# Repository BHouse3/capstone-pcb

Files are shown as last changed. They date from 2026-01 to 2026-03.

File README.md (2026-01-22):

# capstone-pcb

All files and documentation for PCB integration.

## Timeline

01/12/2026 - Created project repo and initial hierarchical KiCad structure. Found DFRobot's rp2350 module footprint.

01/13/2026 - Ethan created symbol for rp2350 module.

01/14/2026 - Created fuel gauge schematic with LC709203FQH-01TWG. Evaluating charging and voltage conversion methodology. 

01/15/2026 - Redesign of entire power subsystem. Utilizing TP4057 charger on board RP2350 module. DW01A + FS8205A protection circuitry. TPS61023 5V boost converter. BQ27441-G1 fuel gauge. Minimizes cost and number of components in power system. Ethan created L1 schematic with labels and wires for the symbol created on 01/13/2026. The symbol was also edited to correct labeling errors.

01/17/2026 - Power schematic starting point based on datasheet implementations. Will work to further verify. Changed MCU labels to global labels.

01/20/2026 - UI schematic finished. External connector symbols added. Hierarchical label issue. Washout detection schematic finished. Motor schematic finished.

01/22/2026 - Fixed critical polarity issue on flyback diodes. Hierarchical label assignment. Added missing I2C labels on power system

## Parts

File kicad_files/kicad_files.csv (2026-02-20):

Reference | Qty | Value | DNP | Exclude from BOM | Exclude from Board | Footprint | Datasheet
.1 | 1 | DFRobot RP2350 Module |  |  |  | rp2350_footprint:DFR1188-DIP
C2 | 1 | 1.0uF
C3,C10 | 2 | 10uF |  |  |  |  | ~
C4 | 1 | 0.47uF
C5,C6 | 2 | 22uF
C7,C8,C9 | 3 | 10nF |  |  |  |  | ~
C11 | 1 | 1uF |  |  |  |  | ~
C12 | 1 | 220 uF
C14 | 1 | 0.1uF
D1 | 1 | 1N4001 |  |  |  | Diode_THT:D_DO-41_SOD81_P10.16mm_Horizontal | http://www.vishay.com/docs/88503/1n4001.pdf
D3 | 1 | 1N914 |  |  |  | Diode_THT:D_DO-35_SOD27_P7.62mm_Horizontal | http://www.vishay.com/docs/85622/1n914.pdf
J1 | 1 | Battery Connection |  |  |  |  | ~
J2,J6 | 2 | Servo Connection |  |  |  |  | ~
J3 | 1 | DC Motor Connection |  |  |  |  | ~
J4 | 1 | Washout Ultrasonic Sensor Connection |  |  |  |  | ~
J5 | 1 | Water Sensor Connection |  |  |  |  | ~
J7 | 1 | Larvicide Level Ultrasonic Sensor Connection |  |  |  |  | ~
L1 | 1 | 1uH |  |  |  |  | ~
Q1 | 1 | FS8205A |  |  |  | Fs8205a:SOT-23-6L_TCP | FS8205A
Q2,Q3,Q4,Q5,Q7 | 5 | NMOS |  |  |  |  | https://ngspice.sourceforge.io/docs/ngspice-html-manual/manual.xhtml#cha_MOSFETs
R1 | 1 | 100 |  |  |  |  | ~
R2 | 1 | 1000 |  |  |  |  | ~
R3,R4,R5 | 3 | 5100 |  |  |  |  | ~
R6,R10,R11,R22,R23,R24,R30 | 7 | 10k |  |  |  |  | ~
R7 | 1 | 0.01 / 1% |  |  |  |  | ~
R8 | 1 | 732k |  |  |  |  | ~
R9,R13,R16,R17,R18,R19 | 6 | 100k |  |  |  |  | ~
R12,R21,R26,R27 | 4 | 1k |  |  |  |  | ~
R14 | 1 | 200k |  |  |  |  | ~
R15 | 1 | 470k |  |  |  |  | ~
R20 | 1 | 20k |  |  |  |  | ~
R28,R29 | 2 | 2k |  |  |  |  | ~
U1 | 1 | BQ27441DRZR-G1A |  |  |  | Package_SON:Texas_S-PDSO-N12 | http://www.ti.com/lit/ds/symlink/bq27441-g1.pdf
U2 | 1 | DW01A |  |  |  | Package_TO_SOT_SMD:SOT-23-6 | https://hmsemi.com/downfile/DW01A.PDF
U3 | 1 | TPS61023DRLR |  |  |  | TPS61023:DRL0006A | https://www.ti.com/lit/gpn/tps61023
U4 | 1 | LM311 |  |  |  | LM311:D8 | https://www.st.com/resource/en/datasheet/lm311.pdf
U5,U6 | 2 | LMC555CMMX_NOPB |  |  |  | LMC555CMMX_NOPB:SOP65P490X110-8N

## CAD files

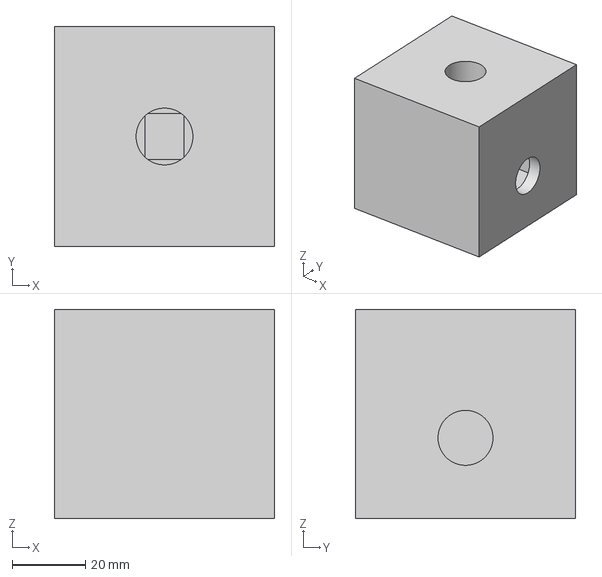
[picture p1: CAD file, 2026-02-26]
LarvicideDispersionSubsystem(2-25-2026)/Assembly 1 - Motor Housing.3mf
60.0 x 60.0 x 57.0 mm

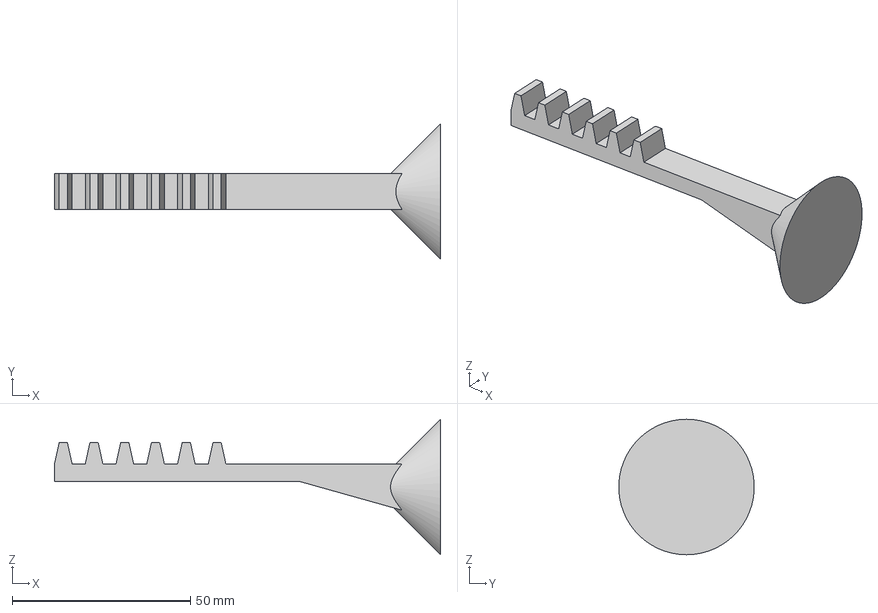
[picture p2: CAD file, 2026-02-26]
LarvicideDispersionSubsystem(2-25-2026)/Assembly 1 - Rack.3mf
108.4 x 38.0 x 38.1 mm

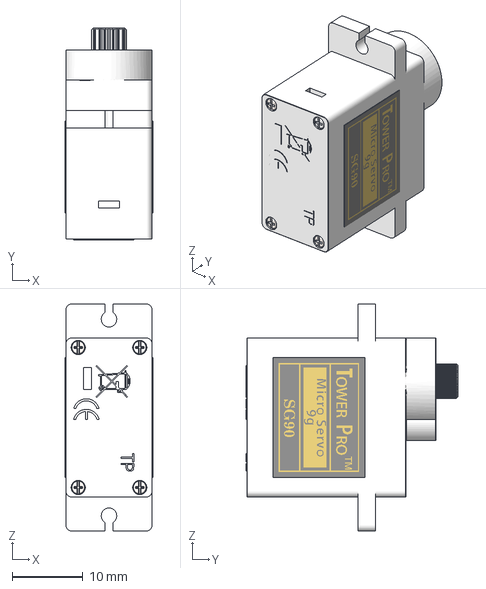
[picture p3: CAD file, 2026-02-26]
LarvicideDispersionSubsystem(2-25-2026)/Assembly 1 - Servo.3mf
12.4 x 29.9 x 32.1 mm

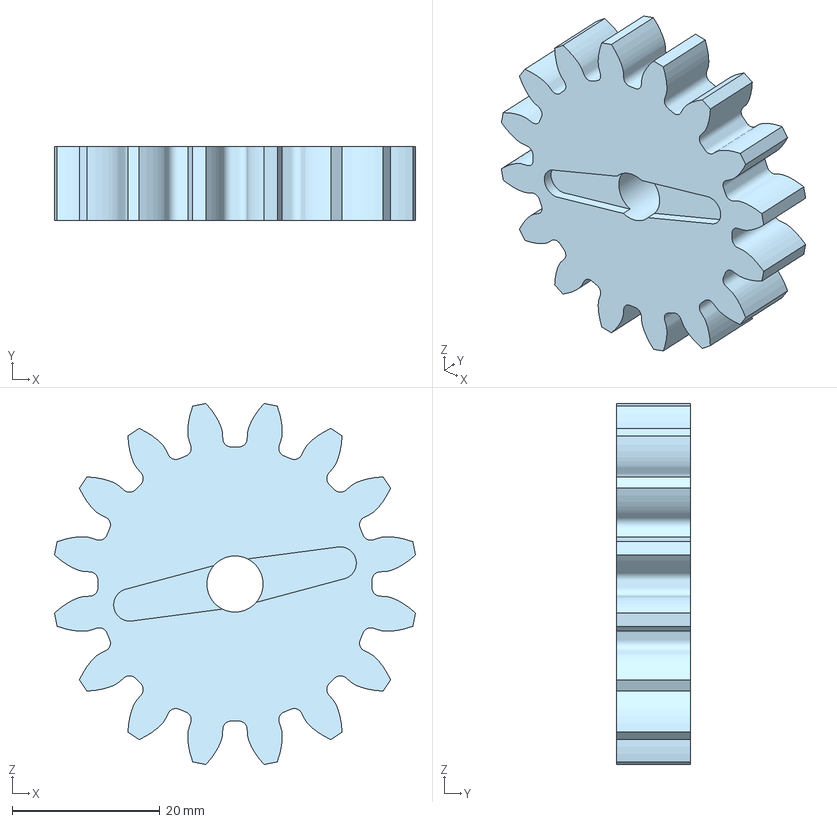
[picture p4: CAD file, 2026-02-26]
LarvicideDispersionSubsystem(2-25-2026)/Assembly 1 - Spur gear (16 teeth).3mf
48.9 x 10.0 x 48.9 mm

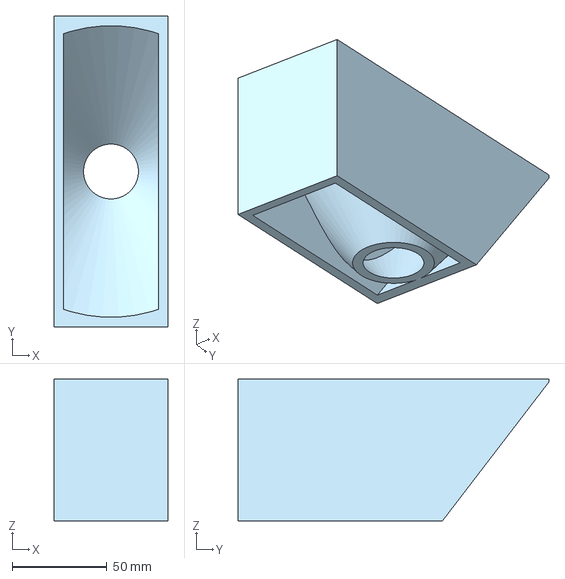
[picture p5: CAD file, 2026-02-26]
LarvicideDispersionSubsystem(2-25-2026)/Assembly 1 - Part 1.3mf
60.0 x 164.0 x 75.0 mm

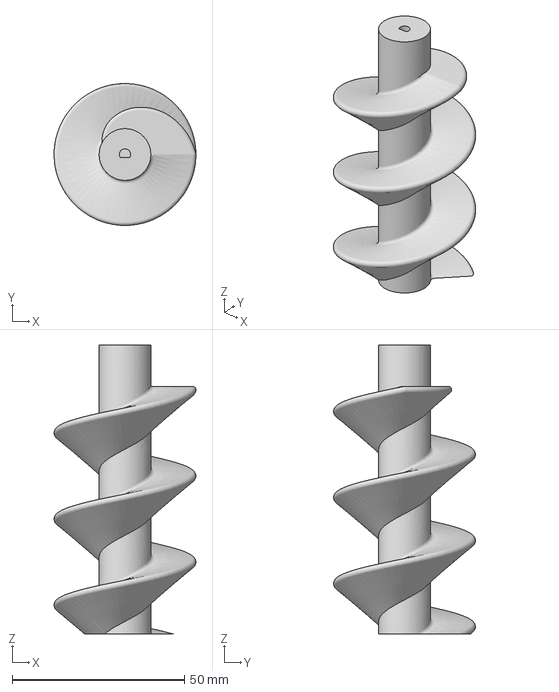
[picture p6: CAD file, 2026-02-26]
LarvicideDispersionSubsystem(2-25-2026)/Assembly 1 - Part 5.3mf
41.2 x 41.2 x 83.9 mm

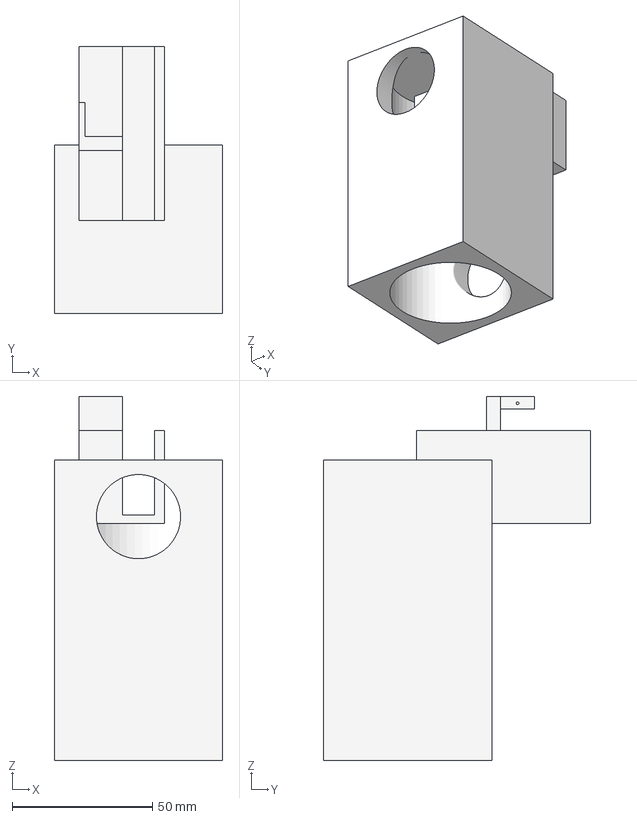
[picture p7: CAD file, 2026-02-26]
LarvicideDispersionSubsystem(2-25-2026)/Assembly 1 - Auger Casing.3mf
60.0 x 95.0 x 129.7 mm

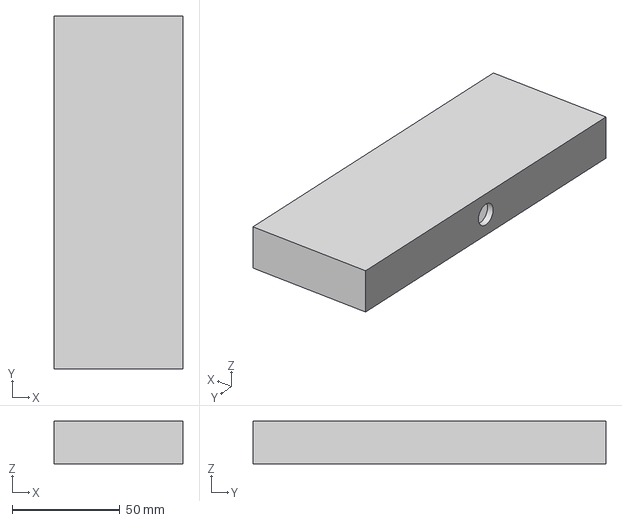
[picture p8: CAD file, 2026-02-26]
LarvicideDispersionSubsystem(2-25-2026)/Assembly 1 - Part 2.3mf
60.0 x 164.0 x 20.0 mm

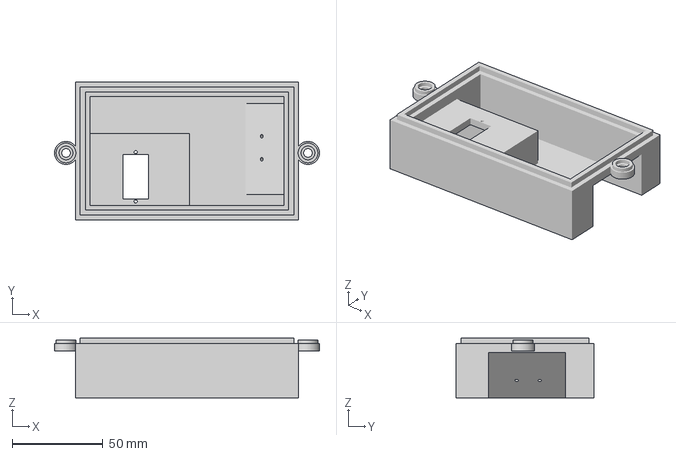
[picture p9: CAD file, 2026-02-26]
Current Housing Degin/Part Studio 1 - Housing Top.3mf
146.1 x 76.0 x 33.0 mm

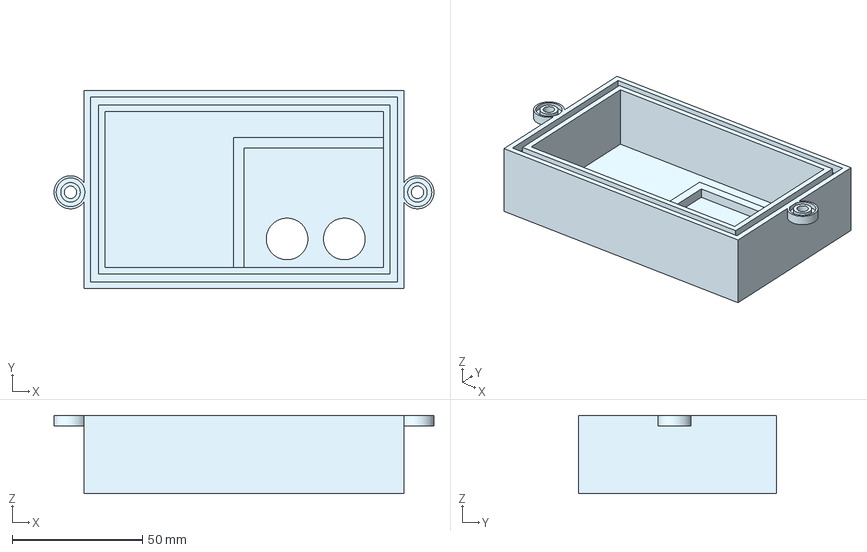
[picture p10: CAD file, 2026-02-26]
Current Housing Degin/Part Studio 1 - Housing Bottom.3mf
146.0 x 76.0 x 30.0 mm

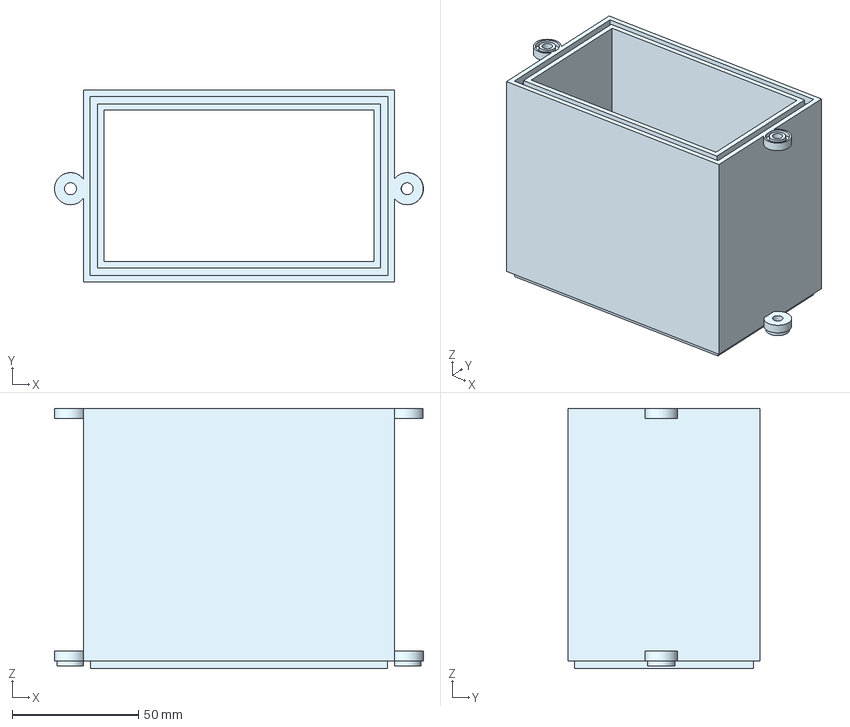
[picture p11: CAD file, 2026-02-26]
Current Housing Degin/Part Studio 1 - Housing Middle.3mf
146.1 x 76.0 x 103.0 mm

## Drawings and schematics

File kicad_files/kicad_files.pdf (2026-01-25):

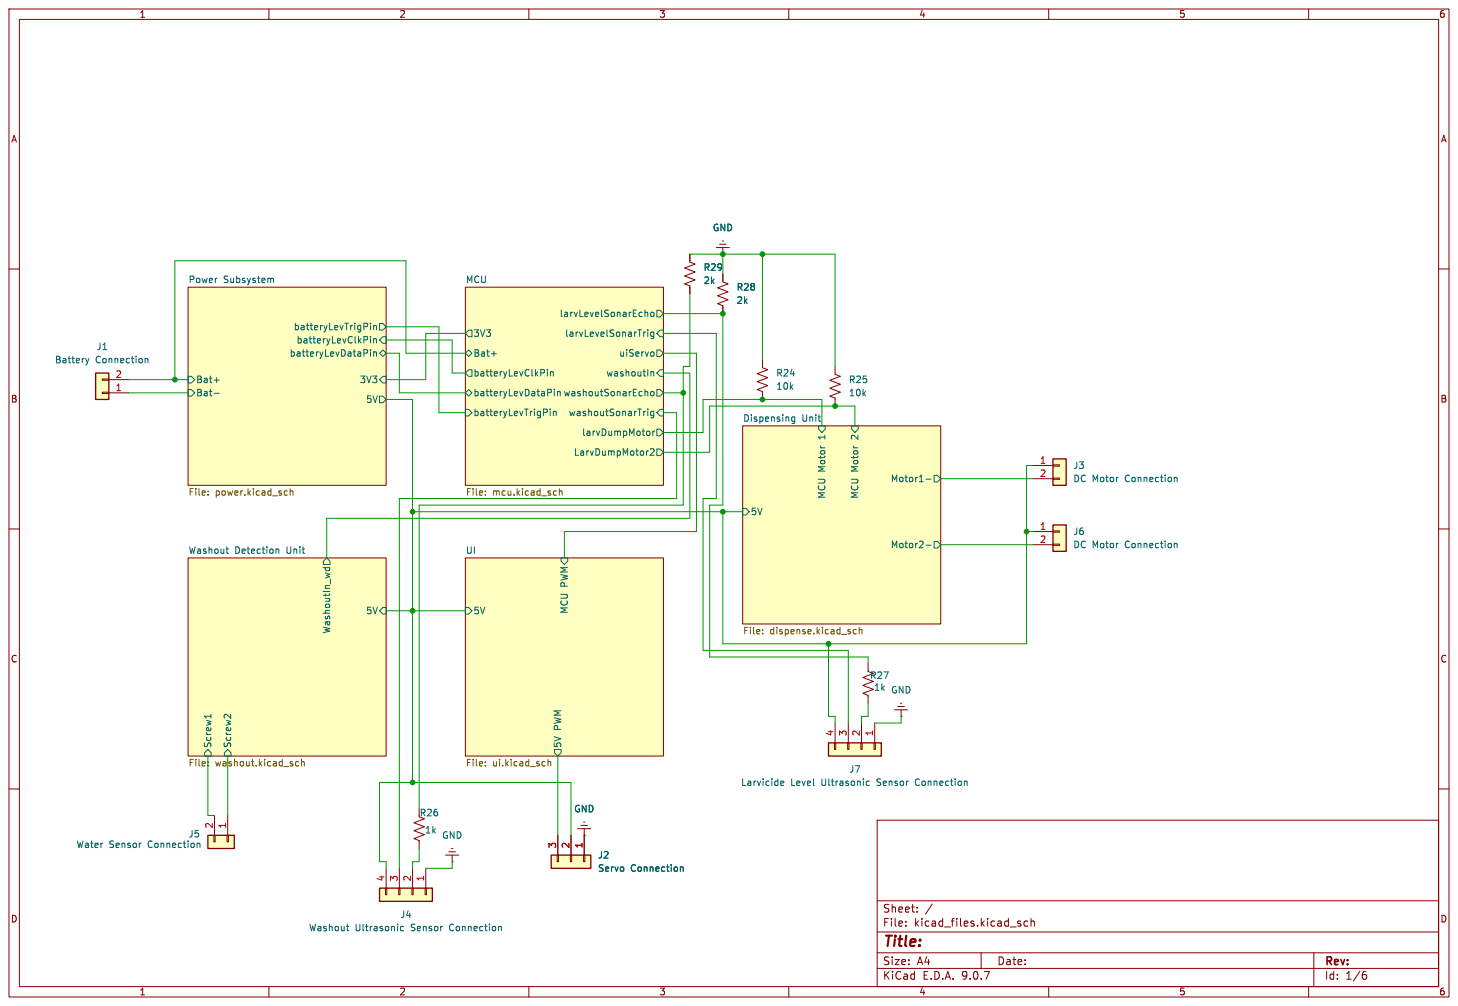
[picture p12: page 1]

larvLevelSonarEcho
larvLevelSonarTrig
uiServo washoutIn washoutSonarEcho washoutSonarTrig

Id: 1/6 Title: File: kicad_files.kicad_sch Sheet: /

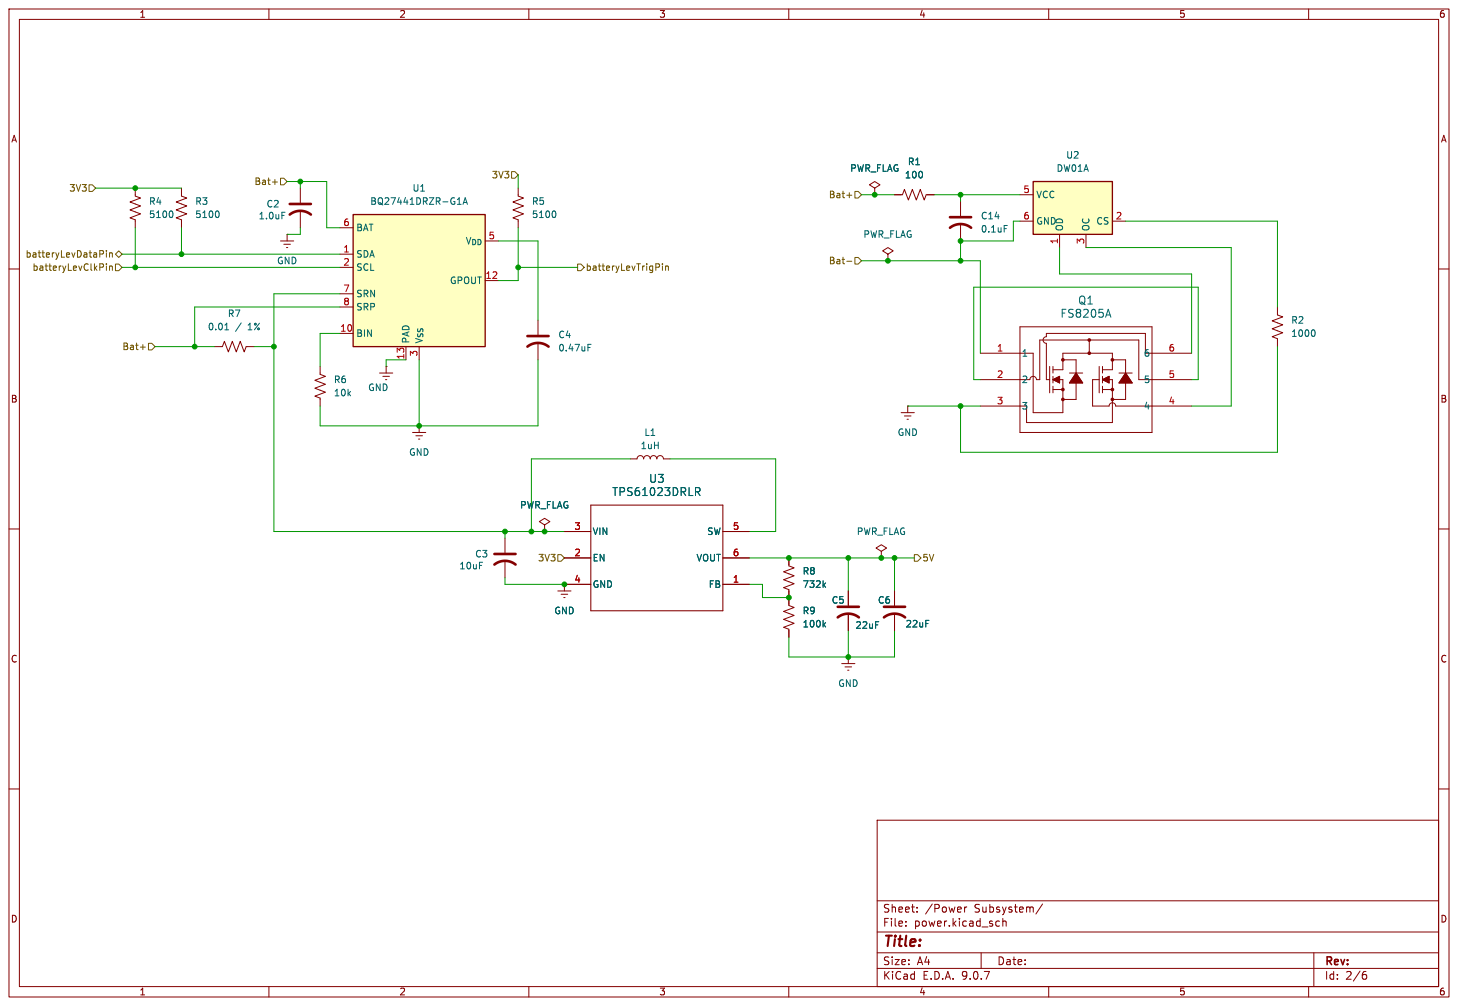
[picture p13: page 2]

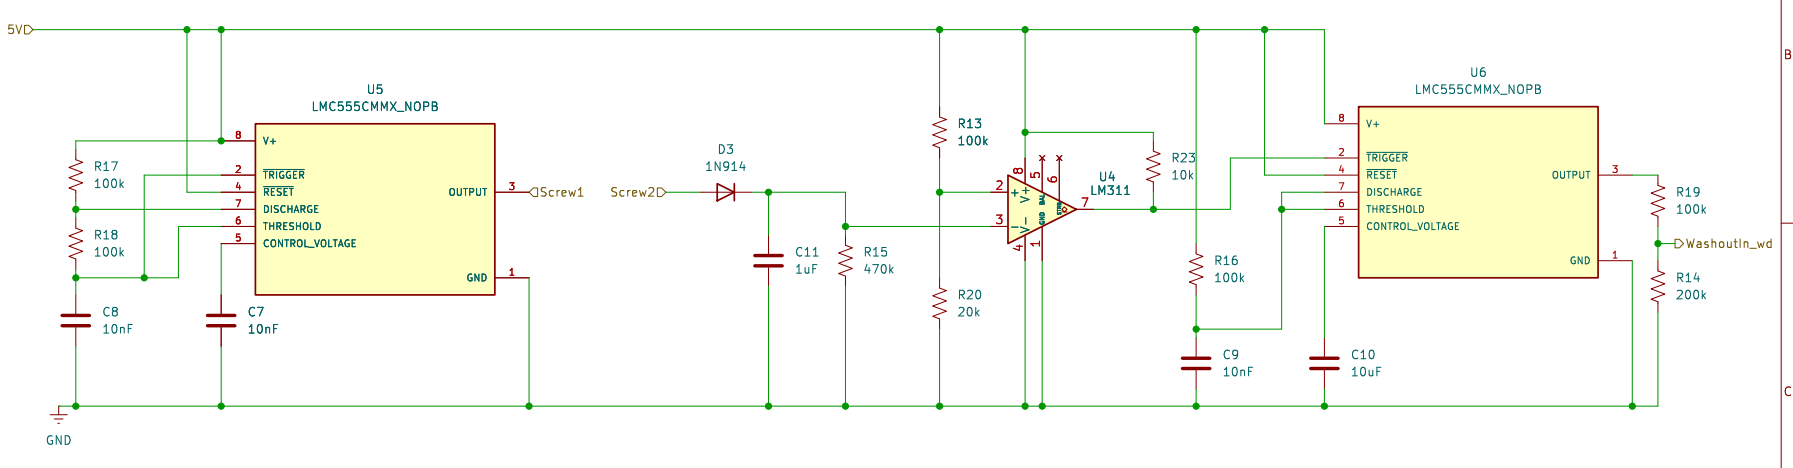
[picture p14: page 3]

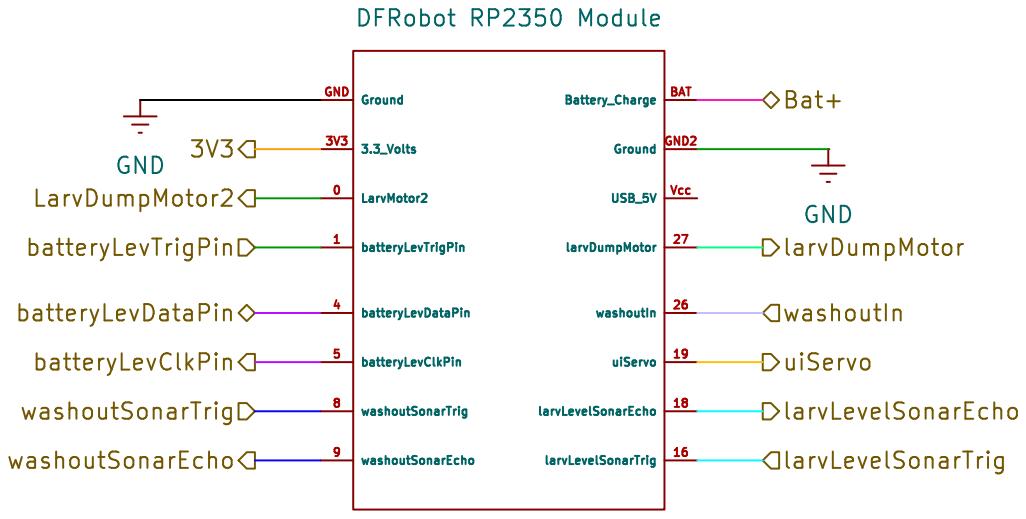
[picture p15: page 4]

Id: 4/6 Title: File: mcu.kicad_sch Sheet: /MCU/

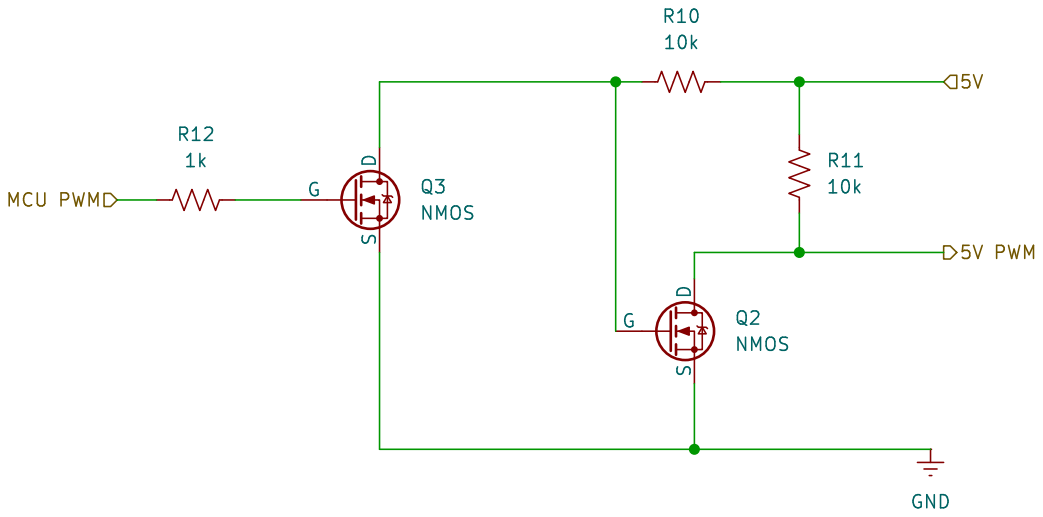
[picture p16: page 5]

Id: 5/6 Title: File: ui.kicad_sch Sheet: /UI/ G

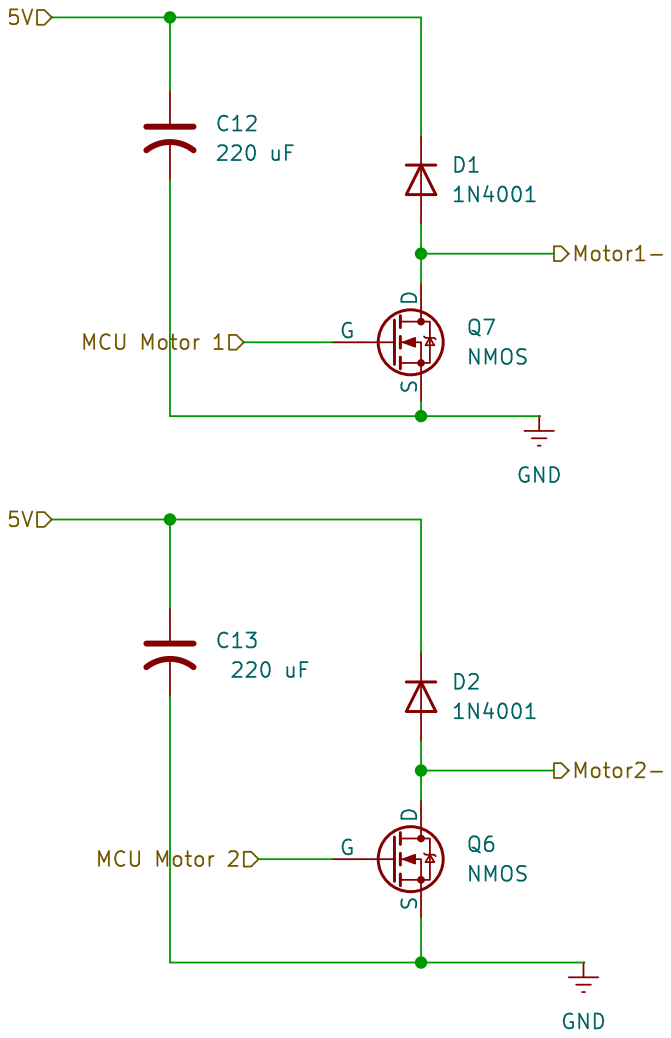
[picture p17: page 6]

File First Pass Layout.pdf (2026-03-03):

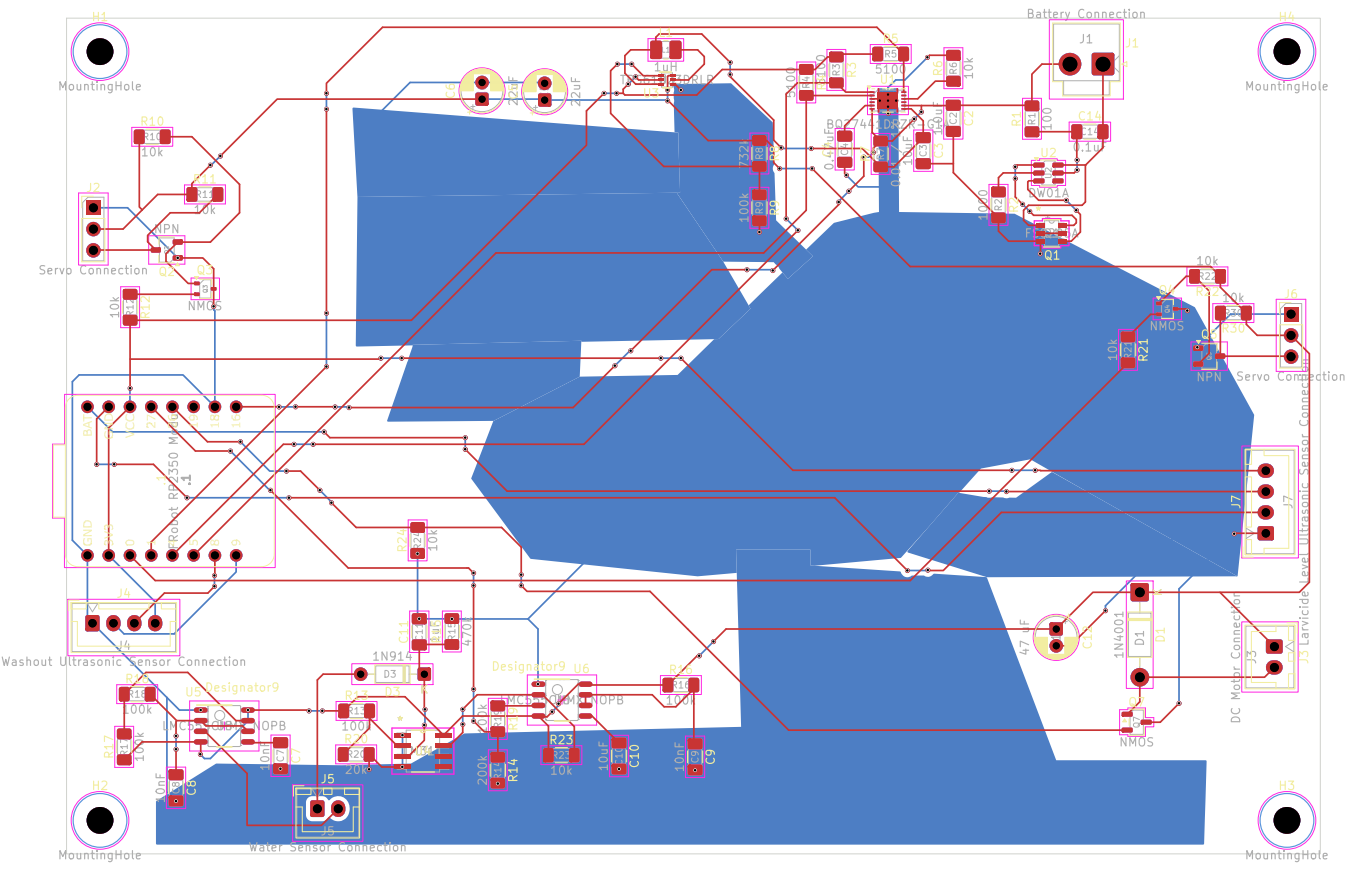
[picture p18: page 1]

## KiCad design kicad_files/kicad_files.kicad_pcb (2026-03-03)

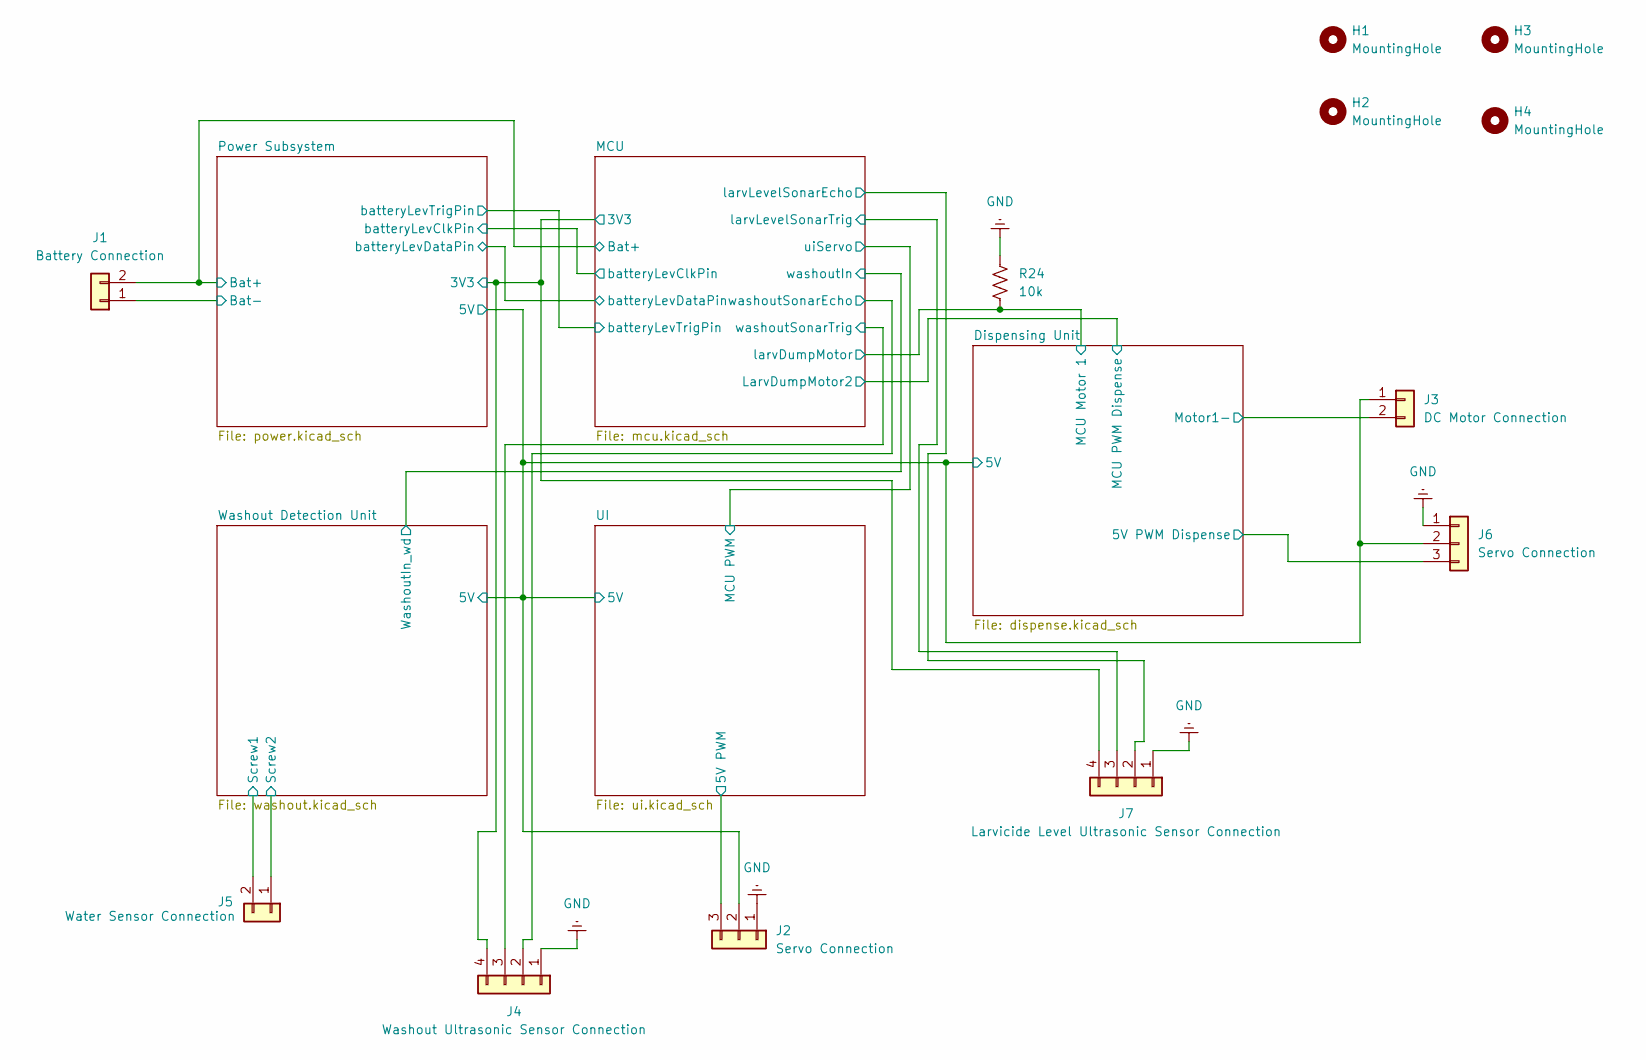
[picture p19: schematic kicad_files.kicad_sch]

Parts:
H1, H2, H3, H4: MountingHole; MountingHole_3.2mm_M3
J1: Battery Connection; JST_VH_B2P-VH_1x02_P3.96mm_Vertical
J2, J6: Servo Connection; PinHeader_1x03_P2.54mm_Vertical
J3: DC Motor Connection; JST_XH_B2B-XH-A_1x02_P2.50mm_Vertical
J4: Washout Ultrasonic Sensor Connection; JST_XH_B4B-XH-A_1x04_P2.50mm_Vertical
J5: Water Sensor Connection; JST_XH_B2B-XH-A_1x02_P2.50mm_Vertical
J7: Larvicide Level Ultrasonic Sensor Connection; JST_XH_B4B-XH-A_1x04_P2.50mm_Vertical
R24: 10k; R_1206_3216Metric_Pad1.30x1.75mm_HandSolder

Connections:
/Dispensing Unit/5V: J2.2, J3.1, J6.2; also elsewhere on the board
/Dispensing Unit/5V PWM Dispense: J6.3; also elsewhere on the board
/Dispensing Unit/MCU Motor 1: R24.2; also elsewhere on the board
/Dispensing Unit/Motor1-: J3.2; also elsewhere on the board
/MCU/3V3: J4.4, J7.4; also elsewhere on the board
/MCU/Bat+: J1.2; also elsewhere on the board
/MCU/larvLevelSonarEcho: J7.2; also elsewhere on the board
/MCU/larvLevelSonarTrig: J7.3; also elsewhere on the board
/MCU/washoutSonarEcho: J4.2; also elsewhere on the board
/MCU/washoutSonarTrig: J4.3; also elsewhere on the board
/Power Subsystem/Bat-: J1.1; also elsewhere on the board
/UI/5V PWM: J2.3; also elsewhere on the board
/Washout Detection Unit/Screw1: J5.2; also elsewhere on the board
/Washout Detection Unit/Screw2: J5.1; also elsewhere on the board
GND: J2.1, J4.1, J6.1, J7.1, R24.1; also elsewhere on the board

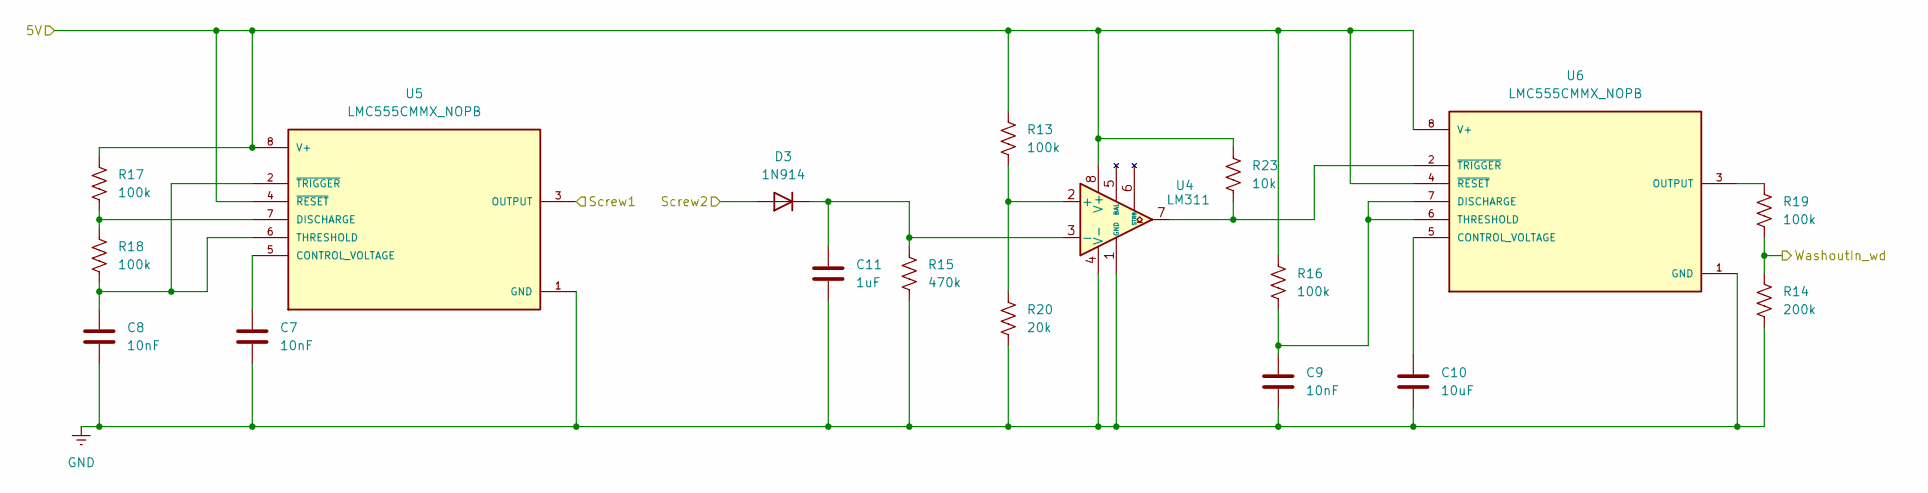
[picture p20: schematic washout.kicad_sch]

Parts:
C7, C8, C9: 10nF; C_1206_3216Metric_Pad1.33x1.80mm_HandSolder
C10: 10uF; C_1206_3216Metric_Pad1.33x1.80mm_HandSolder
C11: 1uF; C_1206_3216Metric_Pad1.33x1.80mm_HandSolder
D3: 1N914; D_DO-35_SOD27_P7.62mm_Horizontal
R13, R16, R17, R18, R19: 100k; R_1206_3216Metric_Pad1.30x1.75mm_HandSolder
R14: 200k; R_1206_3216Metric_Pad1.30x1.75mm_HandSolder
R15: 470k; R_1206_3216Metric_Pad1.30x1.75mm_HandSolder
R20: 20k; R_1206_3216Metric_Pad1.30x1.75mm_HandSolder
R23: 10k; R_1206_3216Metric_Pad1.30x1.75mm_HandSolder
U4: LM311; D8
U5, U6: LMC555CMMX_NOPB; D0008A_M; PARTREV M

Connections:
/Dispensing Unit/5V: R13.1, R16.1, R17.1, R23.1, U4.8 (V+), U5.4 (~RESET), U5.8 (V+), U6.4 (~RESET), U6.8 (V+); also elsewhere on the board
/MCU/washoutIn: R14.1, R19.2; also elsewhere on the board
/Washout Detection Unit/Screw1: U5.3 (OUTPUT); also elsewhere on the board
/Washout Detection Unit/Screw2: D3.2 (A); also elsewhere on the board
GND: C7.2, C8.2, C9.2, C10.2, C11.2, R14.2, R15.2, R20.2, U4.1 (GND), U4.4 (V-), U5.1 (GND), U6.1 (GND); also elsewhere on the board
unnamed: C11.1, D3.1 (K), R15.1, U4.3 (-)
unnamed: R13.2, R20.1, U4.2 (+)
unnamed: C7.1, U5.5 (CONTROL_VOLTAGE)
unnamed: R17.2, R18.1, U5.7 (DISCHARGE)
unnamed: C8.1, R18.2, U5.2 (~TRIGGER), U5.6 (THRESHOLD)
unnamed: C10.1, U6.5 (CONTROL_VOLTAGE)
unnamed: C9.1, R16.2, U6.6 (THRESHOLD), U6.7 (DISCHARGE)
unnamed: R19.1, U6.3 (OUTPUT)
unnamed: R23.2, U4.7, U6.2 (~TRIGGER)

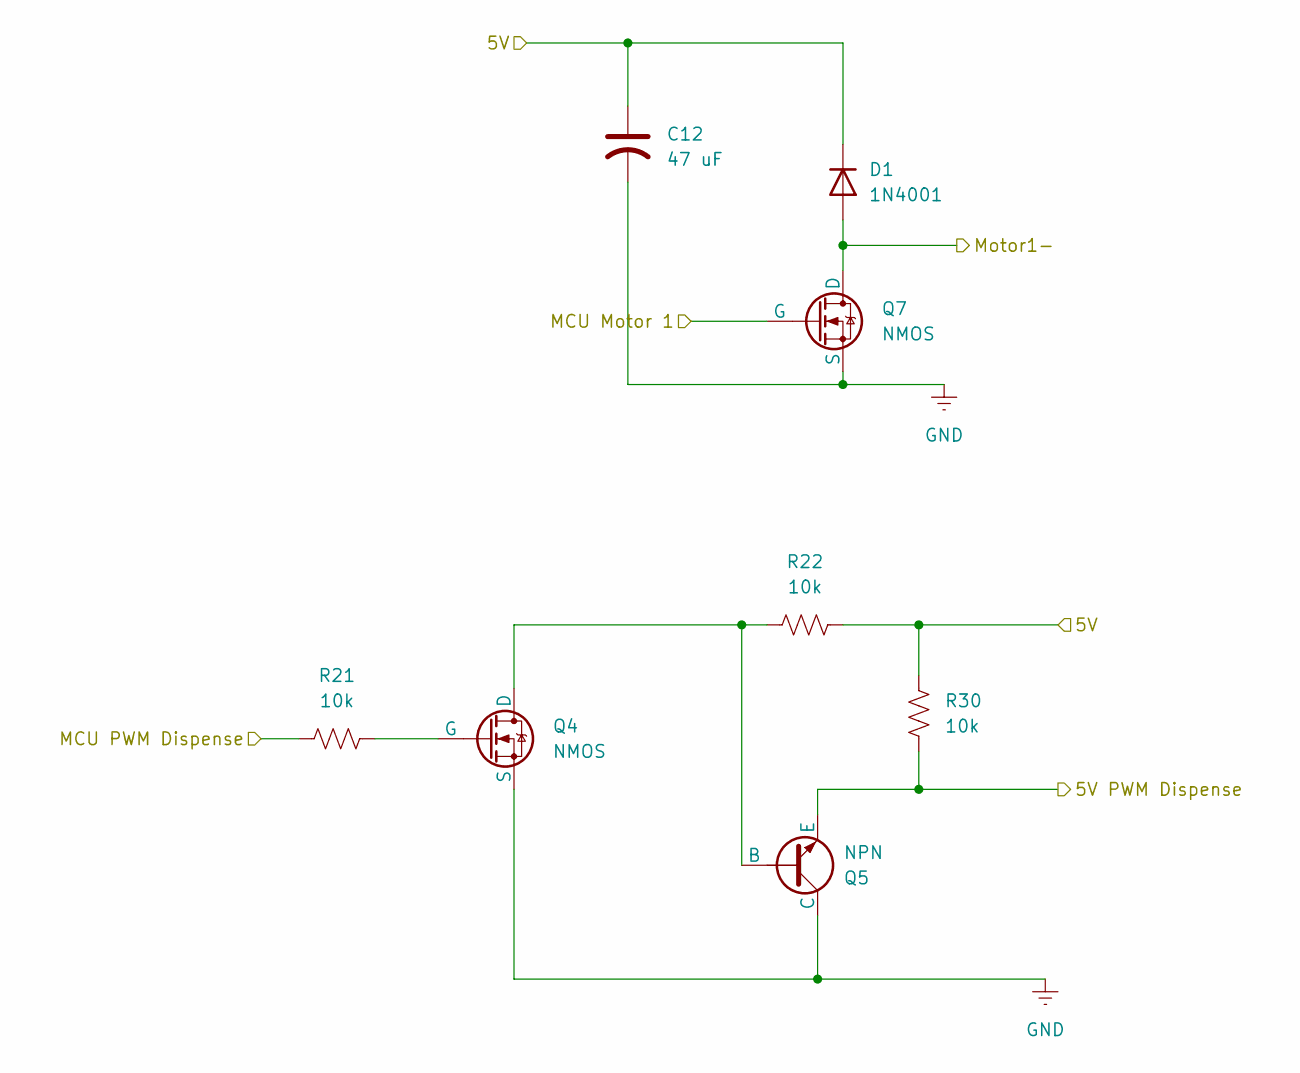
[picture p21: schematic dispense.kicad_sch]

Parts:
C12: 47 uF; CP_Radial_D5.0mm_P2.00mm
D1: 1N4001; D_DO-41_SOD81_P10.16mm_Horizontal
Q4: NMOS; SOT-323_SC-70
Q5: NPN; TSOT-23
Q7: NMOS; SOT-23-3
R21, R22, R30: 10k; R_1206_3216Metric_Pad1.30x1.75mm_HandSolder

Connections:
/Dispensing Unit/5V: C12.1, D1.1 (K), R22.1, R30.1; also elsewhere on the board
/Dispensing Unit/5V PWM Dispense: Q5.3 (E), R30.2; also elsewhere on the board
/Dispensing Unit/MCU Motor 1: Q7.2 (G); also elsewhere on the board
/Dispensing Unit/MCU PWM Dispense: R21.2; also elsewhere on the board
/Dispensing Unit/Motor1-: D1.2 (A), Q7.1 (D); also elsewhere on the board
GND: C12.2, Q4.3 (S), Q5.1 (C), Q7.3 (S); also elsewhere on the board
unnamed: Q4.1 (D), Q5.2 (B), R22.2
unnamed: Q4.2 (G), R21.1

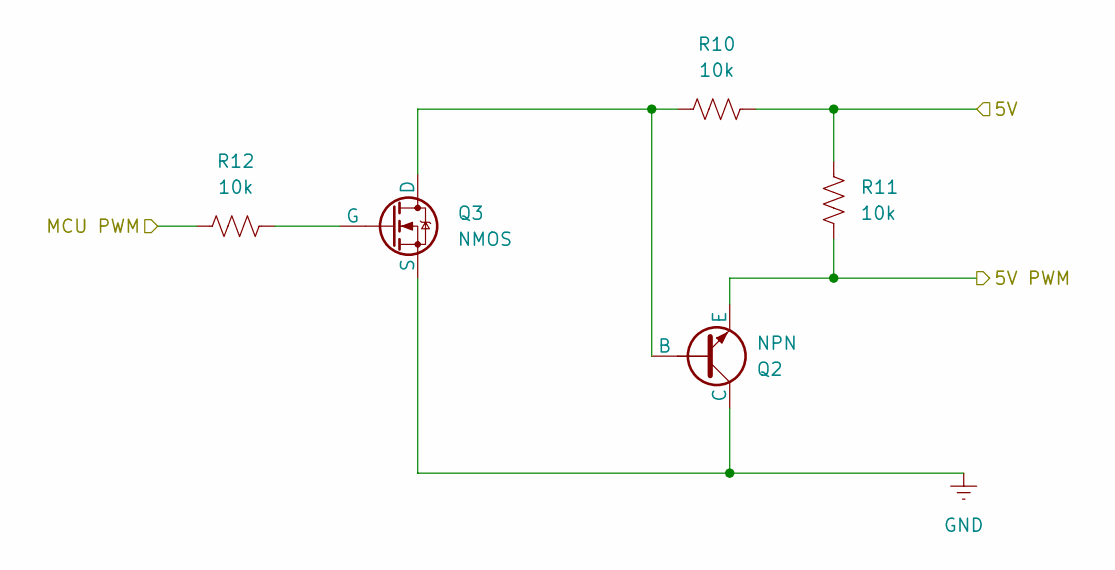
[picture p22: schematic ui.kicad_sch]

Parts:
Q2: NPN; TSOT-23
Q3: NMOS; SOT-323_SC-70
R10, R11, R12: 10k; R_1206_3216Metric_Pad1.30x1.75mm_HandSolder

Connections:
/Dispensing Unit/5V: R10.1, R11.1; also elsewhere on the board
/MCU/uiServo: R12.2; also elsewhere on the board
/UI/5V PWM: Q2.3 (E), R11.2; also elsewhere on the board
GND: Q2.1 (C), Q3.3 (S); also elsewhere on the board
unnamed: Q2.2 (B), Q3.1 (D), R10.2
unnamed: Q3.2 (G), R12.1

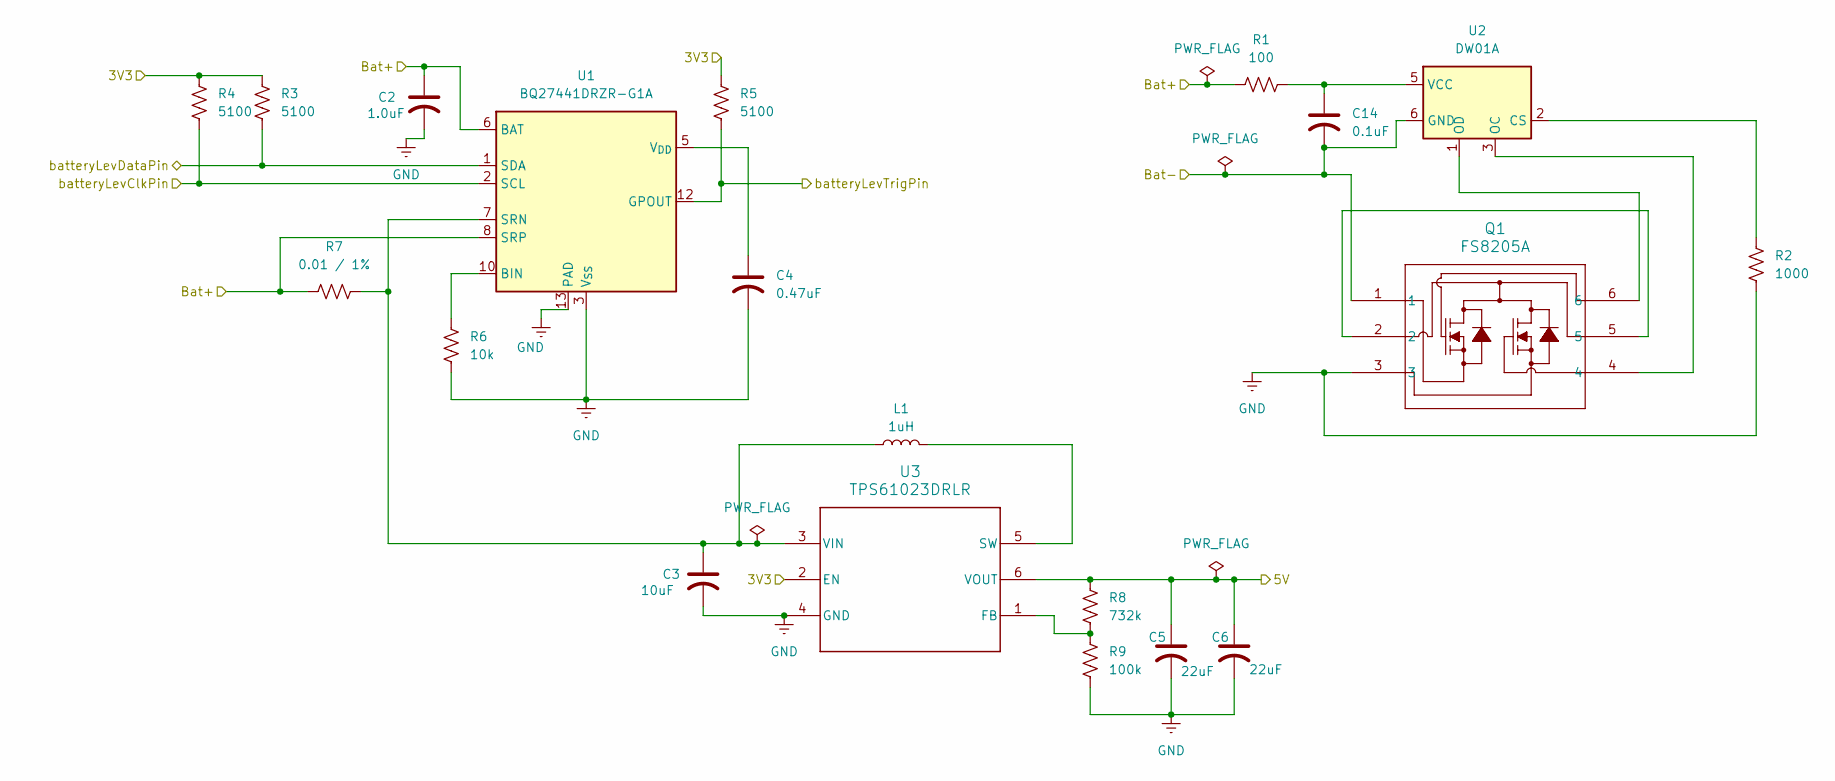
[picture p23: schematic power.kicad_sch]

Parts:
C2: 1.0uF; C_1206_3216Metric_Pad1.33x1.80mm_HandSolder
C3: 10uF; C_1206_3216Metric_Pad1.33x1.80mm_HandSolder
C4: 0.47uF; C_1206_3216Metric_Pad1.33x1.80mm_HandSolder
C5, C6: 22uF; CP_Radial_D5.0mm_P2.00mm
C14: 0.1uF; C_1206_3216Metric_Pad1.33x1.80mm_HandSolder
L1: 1uH; L_1008_2520Metric_Pad1.43x2.20mm_HandSolder
Q1: FS8205A; SOT-23-6L_TCP
R1: 100; R_1206_3216Metric_Pad1.30x1.75mm_HandSolder
R2: 1000; R_1206_3216Metric_Pad1.30x1.75mm_HandSolder
R3, R4, R5: 5100; R_1206_3216Metric_Pad1.30x1.75mm_HandSolder
R6: 10k; R_1206_3216Metric_Pad1.30x1.75mm_HandSolder
R7: 0.01 / 1%; R_1206_3216Metric_Pad1.30x1.75mm_HandSolder
R8: 732k; R_1206_3216Metric_Pad1.30x1.75mm_HandSolder
R9: 100k; R_1206_3216Metric_Pad1.30x1.75mm_HandSolder
U1: BQ27441DRZR-G1A; Texas_S-PDSO-N12
U2: DW01A; SOT-23-6
U3: TPS61023DRLR; DRL0006A

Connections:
/Dispensing Unit/5V: C5.1, C6.1, R8.1, U3.6 (VOUT); also elsewhere on the board
/MCU/3V3: R3.1, R4.1, R5.1, U3.2 (EN); also elsewhere on the board
/MCU/Bat+: C2.1, R1.2, R7.2, U1.6 (BAT), U1.8 (SRP); also elsewhere on the board
/MCU/batteryLevClkPin: R4.2, U1.2 (SCL); also elsewhere on the board
/MCU/batteryLevDataPin: R3.2, U1.1 (SDA); also elsewhere on the board
/MCU/batteryLevTrigPin: R5.2, U1.12 (GPOUT); also elsewhere on the board
/Power Subsystem/Bat-: C14.2, Q1.1, U2.6 (GND); also elsewhere on the board
GND: C2.2, C3.2, C4.2, C5.2, C6.2, Q1.3, R2.2, R6.2, R9.2, U1.3 (V_{SS}), U1.13 (PAD), U3.4 (GND); also elsewhere on the board
unnamed: Q1.2, Q1.5
unnamed: R6.1, U1.10 (BIN)
unnamed: C3.1, L1.1, R7.1, U1.7 (SRN), U3.3 (VIN)
unnamed: C4.1, U1.5 (V_{DD})
unnamed: R2.1, U2.2 (CS)
unnamed: Q1.4, U2.3 (OC)
unnamed: Q1.6, U2.1 (OD)
unnamed: C14.1, R1.1, U2.5 (VCC)
unnamed: R8.2, R9.1, U3.1 (FB)
unnamed: L1.2, U3.5 (SW)

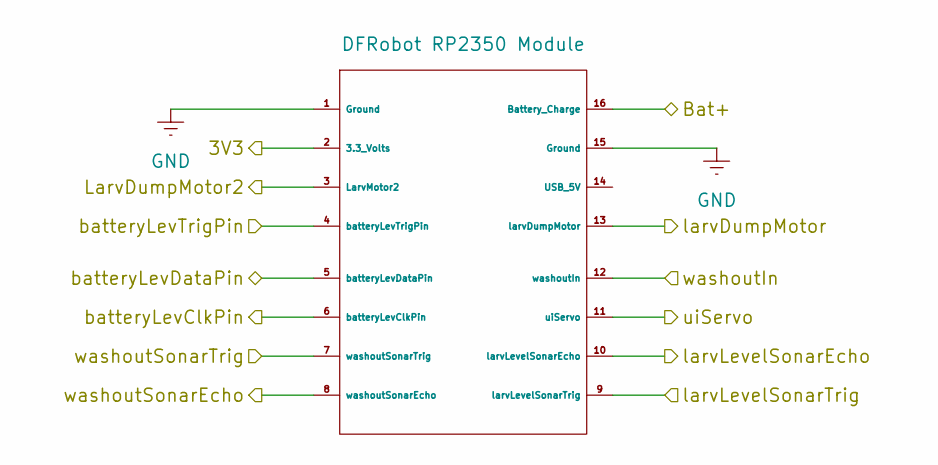
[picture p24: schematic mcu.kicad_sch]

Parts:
.1: DFRobot RP2350 Module; DFR1188-DIP

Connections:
unnamed: .1.1 (Ground), .1.15 (Ground)

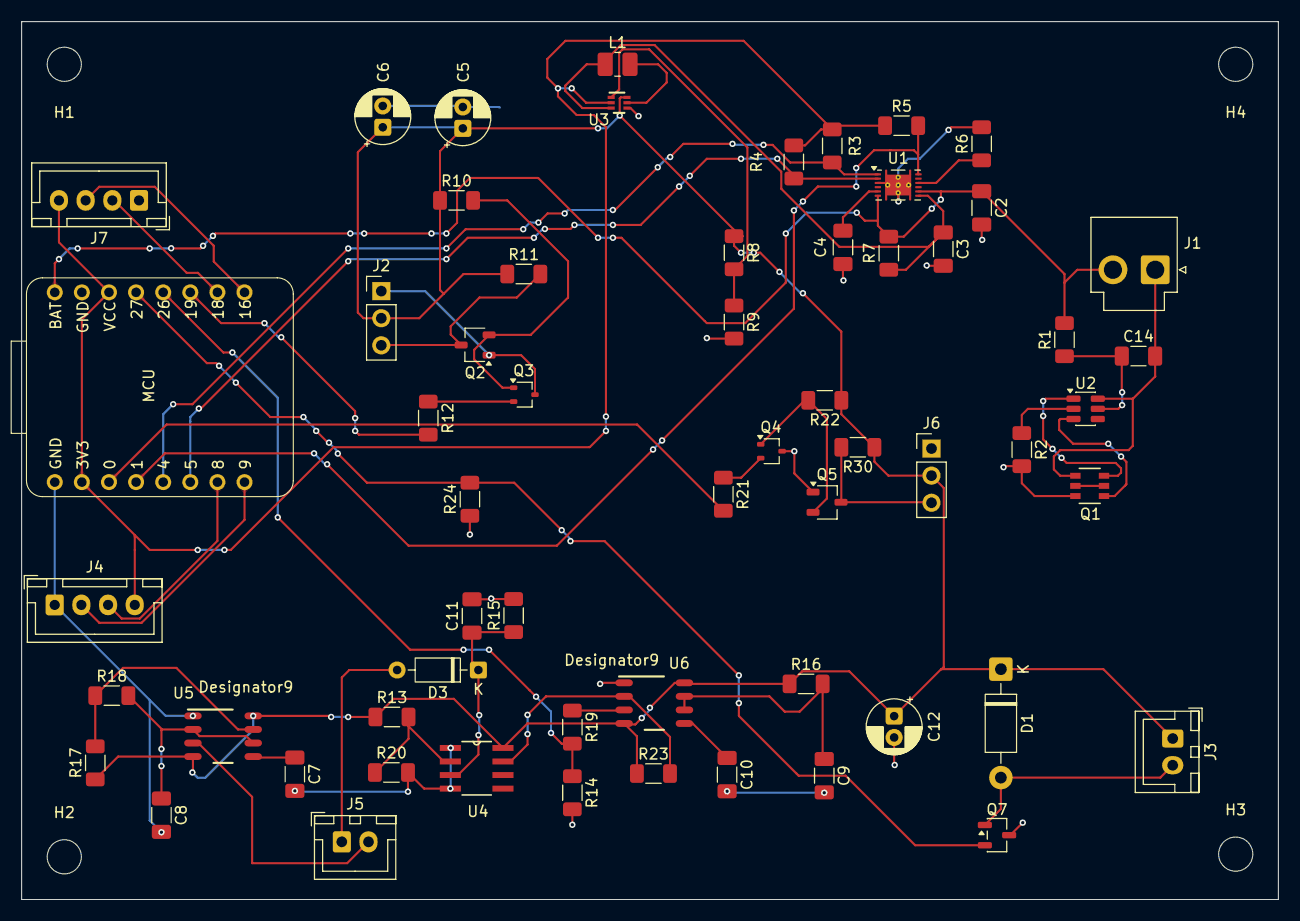
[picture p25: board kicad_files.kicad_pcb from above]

Board: 2 copper layers, 117.8 x 82.2 mm, 64 parts (0 on the bottom side), 44 nets.

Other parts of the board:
MCU: DFRobot RP2350 Module; DFR1188-DIP

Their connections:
/Dispensing Unit/MCU Motor 1: MCU.13 (larvDumpMotor); also elsewhere on the board
/Dispensing Unit/MCU PWM Dispense: MCU.3 (LarvMotor2); also elsewhere on the board
/MCU/3V3: MCU.2 (3.3_Volts); also elsewhere on the board
/MCU/Bat+: MCU.16 (Battery_Charge); also elsewhere on the board
/MCU/batteryLevClkPin: MCU.6 (batteryLevClkPin); also elsewhere on the board
/MCU/batteryLevDataPin: MCU.5 (batteryLevDataPin); also elsewhere on the board
/MCU/batteryLevTrigPin: MCU.4 (batteryLevTrigPin); also elsewhere on the board
/MCU/larvLevelSonarEcho: MCU.10 (larvLevelSonarEcho); also elsewhere on the board
/MCU/larvLevelSonarTrig: MCU.9 (larvLevelSonarTrig); also elsewhere on the board
/MCU/uiServo: MCU.11 (uiServo); also elsewhere on the board
/MCU/washoutIn: MCU.12 (washoutIn); also elsewhere on the board
/MCU/washoutSonarEcho: MCU.8 (washoutSonarEcho); also elsewhere on the board
/MCU/washoutSonarTrig: MCU.7 (washoutSonarTrig); also elsewhere on the board
GND: MCU.1 (Ground), MCU.15 (Ground); also elsewhere on the board

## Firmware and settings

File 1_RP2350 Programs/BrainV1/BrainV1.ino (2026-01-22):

//Project Name: Drain Defenders Processor Code
//Author: Ethan Conrad
//Reason: Control Drain Defenders Device
//Class: EE/CPE 490/491
//History: 10/30/2025 - Start Date
//         11/03/2025 - Adjusted pin definitions to match RP2350 actual pin layout, changed washoutIn to be a
//                      a digital input instead of analog to allow for interrupt usage, and added UI servo motor
//                      logic to work with one servo instead of two, and added servoCheck function to check
//                      servo states for the "both" state
//         11/04/2025 - Asjusted pin definitions to allow battery interrrupt sense to have I2C compatibility
//         11/10/2025 - Changed larvDumpMotor to larvDumpMotor due to realzing the RP2350 pins cannot supply in
//                      rush current needed to turn motor sufficiently. Then updated all code relevant to motor
//                      to digital commands to support MOSFET circuit logic
//         11/11/2025 - Adjusted duration of the low power sleep to be 5 minutes or 300000 ms
//         11/24/2025 - Changed Washout Sensor Interupt to falling edge based on results from testing script
//         12/02/2025 - Included Adafuit library and associated code/logic to enable I2C communication with Power
//                      Distribution subsystem
//         12/03/2025 - B.H.: Added I2C initialization and LC709203F/interrupt communication
//         12/08/2025 - added in set clock and data initialization code to fix I2C errors
//
//Purpose: To create a program that can be used to control the device that the Drain Defenders design for their
//             project sponsor Todd Montgomery. This device should be able to detect water flowing into a
//             water basin and dispense larvicide as needed. This code shall be able to receive and interface
//             with all necessary IO's from the different subsystems and process them correctly.
//////////////////////////////////////////////////////////////////////////////////////////////////////////////////
#include <Servo.h>
#include <Wire.h>
#include "Adafruit_LC709203F.h"

// === Pin Definitions ===
const int washoutIn = 26;       // Digital pin to detect high signal (interrupt) from washout sensor
const int washoutSonarTrig = 8;              // Washout Sonar trigger pin
const int washoutSonarEcho = 9;              // Washout Sonoar echo pin
const int larvLevelSonarTrig = 16;              // Larvicide Level trigger pin (sonar)
const int larvLevelSonarEcho = 18;              // Larvicide Level echo pin (sonar)
const int larvDumpMotor = 27;               // Larvicide Level Dump Motor (PWM pin for N-Type MOSFET)
const int uiServo = 19;                // UI Battery Control Servo Motor
const int batteryLevTrigPin = 1;       // Battery Level Digital Input (interrupt)
const int batteryLevClkPin = 5;       // Battery Level Digital Input (interrupt)
const int batteryLevDataPin = 4;       // Battery Level Digital Input (interrupt)

// === Objects and Globals ===
Servo servoMotor; //Create Servo motor
Adafruit_LC709203F lc; //Create Fuel guage object
volatile bool washoutTrigger = false;   // boolean for washout interrupt trigger
volatile bool batteryTrigger = false; //boolean for battery interrupt trigger
float previousDistance = -1.0;         // Store last distance for washoutSonar, initialized to -1 for system boot
const float larvicideThreshold = 40.0;    // Preprogrammed value for larvicide level
volatile int larveCheck = 0; // Store checking variable for larvicide level
volatile int battCheck = 0; // Store checking variable for battery level
// === Utility: Measure distance from an HC-SR04-style sensor ===
float getSonarDistance(int trigPin, int echoPin) {
  digitalWrite(trigPin, LOW);
  delayMicroseconds(2);
  digitalWrite(trigPin, HIGH);
  delayMicroseconds(10);
  digitalWrite(trigPin, LOW);// Writing Sequences for gaining
  long duration = pulseIn(echoPin, HIGH, 30000); // measure timeout in µs
  Serial.println(duration);
  float distance = (duration * 0.0343) / 2.0;      // ocnvert distance to cm
  return distance;//return distance
}//end getSonarDistance

// === Interrupt handlers ===
//Washout Interupt function
void washoutInterruptHandler() {//removed IRAM_ATTR
Serial.println("Washout Sensed");
  washoutTrigger = true;// flip boolean for execution in main loop
}//end washoutInterruptHandler

void batteryDigitalInterruptHandler() {//removed IRAM_ATTR
Serial.println("Battery Low Sensed");
    batteryTrigger = true;// flip boolean for execution in main loop
}//end batteryDigitialInterruptHandler

// === Utility: Move Servo to Final State if conditon given ===
void servoCheck() {
      if(larveCheck == 1 && battCheck == 1){
            servoMotor.write(100);
            larveCheck = 0;
            //battCheck = 0;
      }//end if
}//end servo check

// === Setup ===
void setup() {
  // Serial optional for debugging
  Serial.begin(9600);
  delay(2000);
  // Configure all pins
  pinMode(washoutIn, INPUT);
  pinMode(washoutSonarTrig, OUTPUT);
  pinMode(washoutSonarEcho, INPUT);
  pinMode(larvLevelSonarTrig, OUTPUT);
  pinMode(larvLevelSonarEcho, INPUT);
  pinMode(larvDumpMotor, OUTPUT);
  digitalWrite(larvDumpMotor, LOW);//Ensure MOSFET is closed at start
  pinMode(batteryLevTrigPin, INPUT_PULLUP);
  Serial.println("Begin Initialize");
 
  Wire.setSDA(batteryLevDataPin);
  Wire.setSCL(batteryLevClkPin);
  Wire.setClock(10000);
  Wire.begin();
  // Attach battery servo to project
  servoMotor.attach(uiServo);
  servoMotor.write(0);  // Start at 0%
  // Set interrupts
  attachInterrupt(digitalPinToInterrupt(batteryLevTrigPin), batteryDigitalInterruptHandler, FALLING);
  attachInterrupt(digitalPinToInterrupt(washoutIn), washoutInterruptHandler, FALLING);
  // Analog interrupt: use pin change or poll threshold
  washoutTrigger = false;
  batteryTrigger = false;
  //
  while (!lc.begin(&Wire)) {
    Serial.println(F("Couldnt find Adafruit LC709203F?\nMake sure a battery is plugged in!"));
    delay(10000);
  }
  Serial.println(F("Found LC709203F"));
  lc.setThermistorB(3950);
  lc.setPackSize(LC709203F_APA_3000MAH);
  lc.setAlarmRSOC(20);

  // Low power setup (optional: external libs like LowPower.h can deepen sleep)
  Serial.println("System initialized, entering low power wait...");
}//end steup function

// === Main loop ===
void loop() {
  // Check if battery is sensed to be low (interrupt trigger)
  if (batteryTrigger) {
    batteryTrigger = false;// reset boolean
    servoMotor.write(33);  // Move servo to 100%
    battCheck = 1;
    delay(1000);//give it time to move
    servoCheck();
  }
  // Check if washout event is sensed (interrupt trigger)
  if (washoutTrigger) {
    washoutTrigger = false; //reset boolean
    //Measure distance from device to water in water basin
    float devToWaterDist = getSonarDistance(washoutSonarTrig, washoutSonarEcho);//store distance in distance variable
    Serial.print("Sonar1 distance: "); Serial.println(devToWaterDist);//debug statement to print data
    if (previousDistance < 0 || abs(devToWaterDist - previousDistance) > 1.0) { // Change detected
      digitalWrite(larvDumpMotor, HIGH); // Run motor full power
      Serial.print("Dispensing Larvicide");
      delay(4000);               // 2 seconds, need to edit for how long a scoop is
      digitalWrite(larvDumpMotor, LOW);   // Stop motor
      // Measure larivicde level
      float sensToLarvDistance = getSonarDistance(larvLevelSonarTrig, larvLevelSonarEcho);//find distance from sonar to larvicide level
      Serial.print("Sonar2 distance: "); Serial.println(sensToLarvDistance);//debug statement to print data
      if (sensToLarvDistance < larvicideThreshold) {//If larvicide is less than threshold indicate it on the UI
         servoMotor.write(66);
         delay(1000);
         larveCheck = 1;
         servoCheck();
      }//end if ()
    }//end if (dispense)
    previousDistance = devToWaterDist;//update and store new distance
  }//end if
  
  // === Low Power Wait ===
  //delay(300000); // short delay; replace with LowPower.sleep() for deep sleep, in ms,
  Serial.println("Sleeping");// This and below delay statement for debugging
  delay(1000);
}

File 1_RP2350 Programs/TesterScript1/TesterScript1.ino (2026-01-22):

//Project Name: Processor Test 2 and 5
//Author: Ethan Conrad
//Reason: Testing RP2350 Processor
//Class: EE/CPE 490/491
//History: 11/17/2025 - Start Date
//
//Purpose: To create a program that can be used to perform the interrupt usage and transistor utilization tests 
//               on the selected processor.
//////////////////////////////////////////////////////////////////////////////////////////////////////////////////
#include <Arduino.h>

// === Pin Assignments ===
const int washoutIn = 26;      // Interrupt input pin (3.3V pulse)
const int led1Sec = 0;         // LED1 (interrupt indicator)
const int larvDumpMotor = 27;  // Motor digital output (pulse)

// === Interrupt Tracking ===
volatile bool interruptTriggered = false;
unsigned long interruptTime = 0;

// === Interrupt Handler ===
void onPulseDetected() {
  interruptTriggered = true;   // Notify main loop
  interruptTime = millis();    // Record time
}

// === Setup ===
void setup() {
  Serial.begin(9600);
  delay(200);
  Serial.println("=== RP2350 Beetle Interrupt Test ===");

  pinMode(led1Sec, OUTPUT);
  digitalWrite(led1Sec, LOW);

  pinMode(larvDumpMotor, OUTPUT);
  digitalWrite(larvDumpMotor, LOW);   // Start LOW

  pinMode(washoutIn, INPUT);
  attachInterrupt(digitalPinToInterrupt(washoutIn), onPulseDetected, RISING);

  Serial.println("Interrupt armed on pin 26 (RISING).");
}

// === Main Loop ===
void loop() {
  unsigned long now = millis();

  // ==========================
  // Test 2: Interrupt Handling
  // ==========================
  if (interruptTriggered) {
    Serial.println("Interrupt detected!");
    digitalWrite(led1Sec, HIGH);
    interruptTriggered = false;
  }

  // Auto-turn-off LED1 after 500 ms
  if (digitalRead(led1Sec) == HIGH && (now - interruptTime >= 500)) {
    digitalWrite(led1Sec, LOW);
    Serial.println("LED1 OFF (auto reset)");
  }

  // ==========================
  // Test 5: BJT Switching
  // ==========================
  const unsigned long HIGH_DURATION = 5000;  // 5 seconds HIGH
  const unsigned long LOW_DURATION  = 5000;  // 5 seconds LOW
  const unsigned long TOTAL_CYCLE   = HIGH_DURATION + LOW_DURATION;

  unsigned long cyclePos = now % TOTAL_CYCLE;

  if (cyclePos < HIGH_DURATION) {
    digitalWrite(larvDumpMotor, HIGH);    // HIGH for 5 seconds
  } else {
    digitalWrite(larvDumpMotor, LOW);     // LOW for 5 seconds
  }
}

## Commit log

2026-01-13 Initial hierarchical project structure with a custom symbol library created.
    [dispense.kicad_sch, kicad_files.kicad_pcb, kicad_files.kicad_sch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]
2026-01-13 DFRobot RP2350 kicad files. Used for footprint assignment
2026-01-14 Kicad files for TPS63021 buck boost regulator IC
    [TPS63021DSJR.step]
2026-01-14 Completed fuel gauge schematic based on application guidance provided in the LC709203F datasheet.
    [lc709203f.kicad_sch, power.kicad_sch, tps63020.kicad_sch]
2026-01-15 FS8205A kicad files
2026-01-15 TPS61023 kicad files
2026-01-15 Revamped power subsystem design
    [TPS63021DSJR.step, power.kicad_sch]
2026-01-15 Deleting unnecessary files
    [lc709203f.kicad_sch, tp4056.kicad_sch, tps63020.kicad_sch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]
2026-01-17 Protection portion of power subsystem
    [power.kicad_sch]
2026-01-18 Initial power system implementation
    [mcu.kicad_sch, power.kicad_sch]
2026-01-20 UI schematic and external connectors
    [kicad_files.kicad_sch, ui.kicad_sch]
2026-01-20 LMC555 symbol and footprint files
    [LMC555CMMX_NOPB.step]
2026-01-20 UI, washout detection, motor schematics finished
    [dispense.kicad_sch, kicad_files.kicad_sch, washout.kicad_sch]
2026-01-22 Hierarchical labels finished. Flyback diode issue fixed. I2C pins added
    [dispense.kicad_sch, kicad_files.kicad_sch, mcu.kicad_sch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]
2026-01-22 LM311 kicad files from TI
2026-01-22 Partial footprint assignment
    [mcu.kicad_sch, power.kicad_sch, washout.kicad_sch]
2026-01-25 ERC errors cleaned. Hierarchical wiring finished. PWM converter change. Motor driver change.
    [dispense.kicad_sch, kicad_files.kicad_sch, mcu.kicad_sch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]
2026-01-25 Updated schematic pdf
2026-02-02 minor changes
    [dispense.kicad_sch, kicad_files.kicad_sch]
2026-02-20 Footprint assignment finished
    [LMC555CMMX_NOPB.step, dispense.kicad_sch, kicad_files.csv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]
2026-02-26 Housing and Dispensing Subsystem Models
    [Assembly 1 - Auger Casing.3mf, Assembly 1 - Motor Housing.3mf, Assembly 1 - Part 1.3mf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]
2026-03-03 First pass floorplan and routing
    [kicad_files.kicad_pcb, kicad_files.kicad_sch]
2026-03-03 First pass revisions
    [kicad_files-B_Cu.gbr, kicad_files-B_Mask.gbr, kicad_files-B_Paste.gbr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]
2026-03-03 Second pass routing and floorplan
    [kicad_files.kicad_pcb]
2026-03-03 Floorplan revisions
    [kicad_files.kicad_pcb]
2026-03-03 Schematic and Footprint error fix
    [kicad_files.kicad_pcb, kicad_files.kicad_sch, mcu.kicad_sch]
